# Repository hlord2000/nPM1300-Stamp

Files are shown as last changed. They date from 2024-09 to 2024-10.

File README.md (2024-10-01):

# nPM1300 Module

<p align="center">
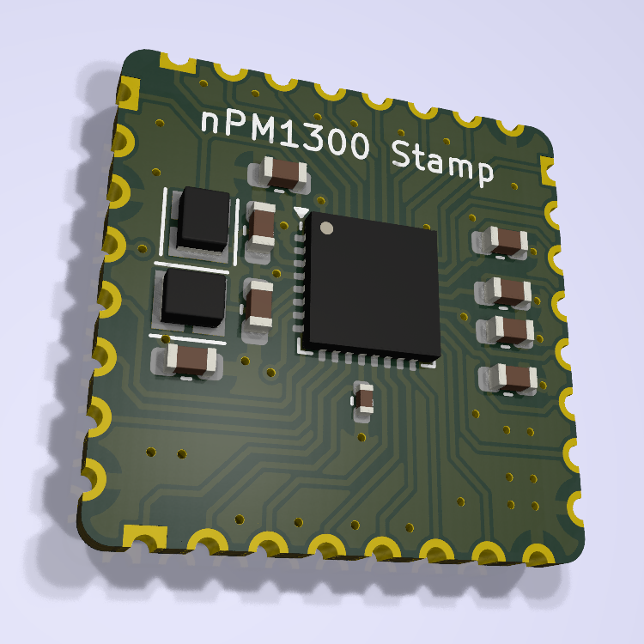
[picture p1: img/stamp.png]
nPM1300 Module
  
</p>

## Overview

Compact module integrating Nordic Semiconductor's nPM1300 PMIC with all necessary passive components. Designed for easy integration into Bluetooth Low Energy embedded systems.

## Key Features

- 800 mA battery charger
- Dual 200 mA buck DCDC regulators
- Fuel gauge functionality
- System-level watchdog
- I2C control interface
- USB-C compatible

## Design Resources

- Schematic symbol available
- PCB footprint available

## Requirements for Design

- VSET1 and VSET2 resistors must be provided externally
- VDDIO must be provided externally, but could also be an output from one of your bucks or LDOs on the nPM1300
- If you use the LDOs, please include the recommended decoupling capacitors outside of the stamp.
- I2C pull-ups are required externally
- ESD protection must be provided externally

For detailed specifications, visit [Nordic Semiconductor's nPM1300 page](https://www.nordicsemi.com/Products/nPM1300).

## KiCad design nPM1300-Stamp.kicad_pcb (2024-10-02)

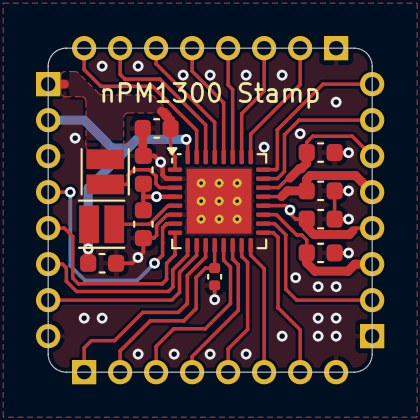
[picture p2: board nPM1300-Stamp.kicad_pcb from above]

Board: 4 copper layers, 18.0 x 18.0 mm, 16 parts (0 on the bottom side), 30 nets.

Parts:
C1: 100nF; C_0402_1005Metric
C2, C3, C4, C7, C8: 10uF; C_0603_1608Metric
C5, C6: 1uF; C_0603_1608Metric
C13: 2.2uF; C_0603_1608Metric
J1, J2, J3, J4: Conn_01x08; nPM1300-PinHeader_1x08_P2.00mm_Vertical
L1, L2: 2.2uH; L_Cenker_CKCS201610
U1: nPM1300-QEXX; QFN-32-1EP_5x5mm_P0.5mm_EP3.6x3.6mm_ThermalVias

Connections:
/CC1: J3.7, U1.23 (CC1)
/CC2: J3.8, U1.24 (CC2)
/GPIO0: J1.4, U1.7 (GPIO0)
/GPIO1: J1.5, U1.8 (GPIO1)
/GPIO2: J1.6, U1.9 (GPIO2)
/GPIO3: J1.7, U1.10 (GPIO3)
/GPIO4: J2.1, U1.11 (GPIO4)
/LED0: J4.2, U1.25 (LED0)
/LED1: J4.3, U1.26 (LED1)
/LED2: J4.4, U1.27 (LED2)
/LS1_IN: J4.5, U1.28 (LSIN1/VINLDO1)
/LS1_OUT: J4.6, U1.29 (LSOUT1/VOUTLDO1)
/LS2_IN: J4.7, U1.30 (LSIN2/VINLDO2)
/LS2_OUT: J4.8, U1.31 (LSOUT2/VOUTLDO2)
/NTC: J3.2, U1.18 (NTC)
/SCL_NPM1300: J2.4, U1.14 (SCL)
/SDA_NPM1300: J2.3, U1.13 (SDA)
/SHPLD: J2.5, U1.15 (SHPHLD)
/VBAT: C13.1, J3.3, U1.19 (VBAT)
/VBUS_IN: C5.1, J3.5, U1.21 (VBUS)
/VBUS_OUT: C6.1, J3.6, U1.22 (VBUSOUT)
/VDDIO: C1.1, J2.2, U1.12 (VDDIO)
/VOUT1: C7.1, J1.1, L1.1, U1.1 (VOUT1)
/VOUT2: C8.1, J1.2, L2.1, U1.32 (VOUT2)
/VSET1: J2.7, U1.17 (VSET1)
/VSET2: J2.6, U1.16 (VSET2)
/VSYS: C2.1, C3.1, C4.1, J3.4, U1.4 (PVDD), U1.20 (VSYS)
GND: C1.2, C2.2, C3.2, C4.2, C5.2, C6.2, C7.2, C8.2, C13.2, J1.3, J1.8, J2.8, J3.1, J4.1, U1.2 (PVSS1), U1.6 (PVSS2), U1.33 (AVSS)
unnamed: L1.2, U1.3 (SW1)
unnamed: L2.2, U1.5 (SW2)

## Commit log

2024-09-30 Added nPM1300 library
    [nPM1300-Stamp.kicad_pcb, nPM1300-Stamp.kicad_sch]
2024-09-30 Added JLCPCB production files
    [nPM1300-Stamp-CuBottom.gbr, nPM1300-Stamp-CuIn1.gbr, nPM1300-Stamp-CuIn2.gbr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]
2024-10-02 Updated layout to use thicker traces for power delivery
    [nPM1300-Stamp-CuBottom.gbr, nPM1300-Stamp-CuIn1.gbr, nPM1300-Stamp-CuIn2.gbr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]
2024-10-02 Updated LCSC part number for 2.2uF cap
    [nPM1300-Stamp-CuBottom.gbr, nPM1300-Stamp-CuIn1.gbr, nPM1300-Stamp-CuIn2.gbr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]
